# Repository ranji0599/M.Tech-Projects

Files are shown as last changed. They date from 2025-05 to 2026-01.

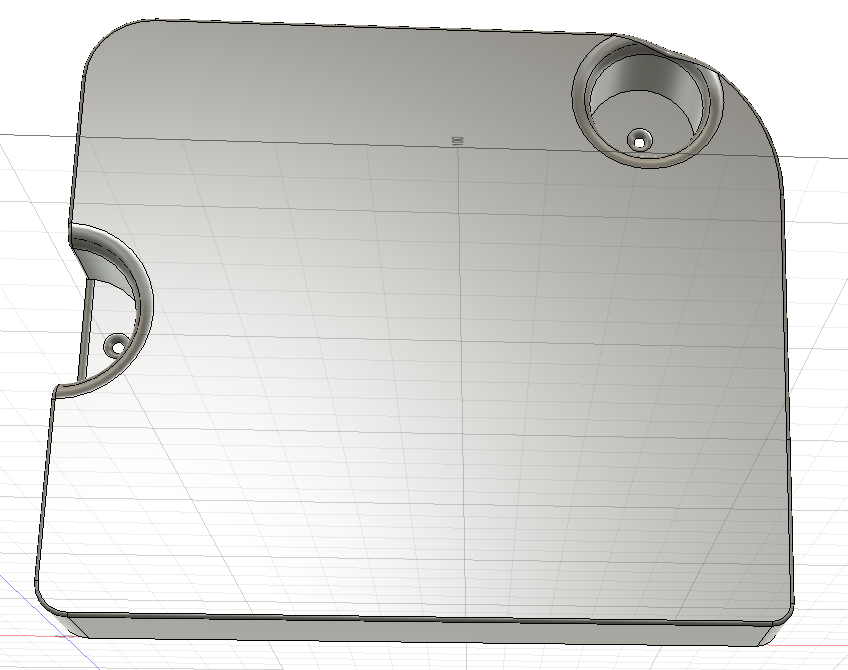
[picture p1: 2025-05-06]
Fusion 360/PNG/Screenshot 2025-03-03 040742.png

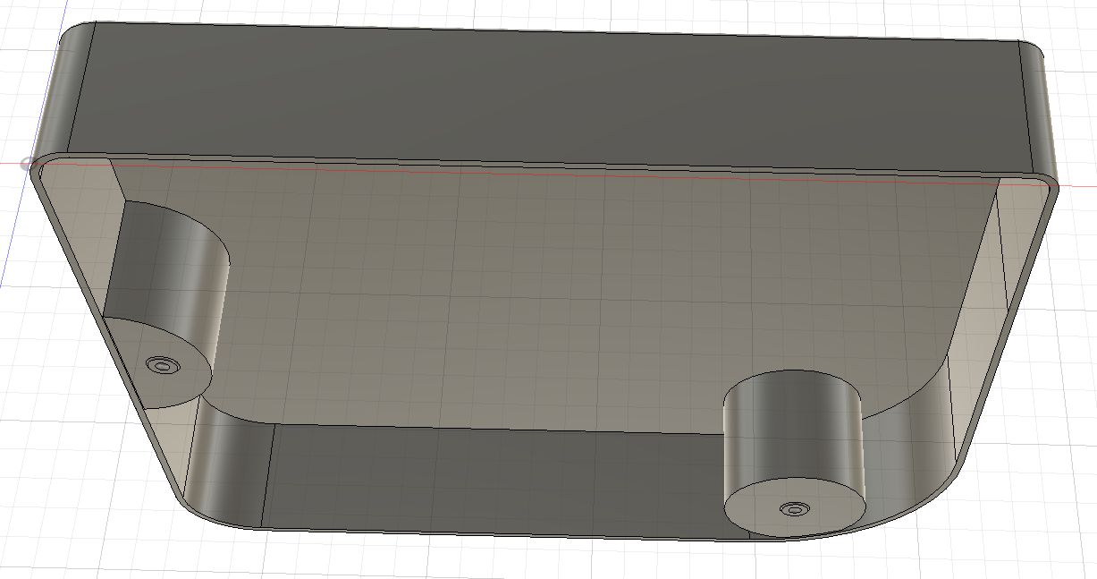
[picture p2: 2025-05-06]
Fusion 360/PNG/Screenshot 2025-03-03 040723.png

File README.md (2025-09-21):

Smart Bed for Pressure Ulcer Prevention

License: MIT Status: Development

IoT-enabled smart bed system that prevents pressure ulcers through automated monitoring and intervention.
Problem

    57-60% of hospitalized patients develop pressure ulcers
    Manual repositioning every 2 hours is labor-intensive
    Current solutions are expensive or require constant monitoring

Solution

Smart bed with automated pressure redistribution using:

    Real-time monitoring: 6 BME280 sensors track pressure, temperature, humidity
    Micro-vibrations: 25-50Hz vibrations improve blood circulation
    Auto-repositioning: Servo motors provide gentle lateral movements
    No manual intervention: Algorithm-driven responses to risk thresholds

Hardware

    ESP32 microcontroller
    6x BME280 sensors
    6x Vibration motors (ERM)
    2x SG90 servo motors
    7.4V LiPo battery
    SD card for data logging

Getting Started
Clone repository:

git clone https:https://github.com/ranji0599/Bed-Sores-Monitoring-Prevention

    Install Thonny IDE and ESP32 support
    Wire components per circuit diagram
    Upload firmware to ESP32
    Mount sensors on bed surface

Project Structure

    Code: Main control program in src/ folder
    Components: Complete parts list in Docs/Components
    Circuit Design: KiCAD files in Hardware/circuit-design/
    3D Casing: Fusion360 models in Hardware/casing/
    Documentation: Project docs in Docs/ folder

License

MIT License - see LICENSE file

⚠️ Disclaimer: Research prototype for educational purposes. Clinical validation required before medical use.

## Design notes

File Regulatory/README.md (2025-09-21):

# Bedsore Monitoring & Prevention System  

This repository contains **regulatory documentation samples** and **technical files** for a TRL-4 prototype developed at IIT Guwahati.  
The project focuses on preventing **pressure ulcers (bedsores)** through continuous monitoring of high-pressure regions.  

## Project Highlights
- Electronics and PCB designed using **KiCAD & Fusion 360**.  
- Firmware implemented on microcontrollers with real-time monitoring and alerts.  
- Documentation aligned with **FDA Class II**, **EU MDR Class IIa**, and **CDSCO monitoring device** pathways.  

## Repository Structure
- `Technical_Dossier.md` – Device description, intended use, and regulatory pathway mapping.  
- `Usability_Engineering_Report.md` – Human factors engineering analysis.  
- `Risk_Management_File_ISO14971.md` – Hazard identification and control measures.  
- `Verification_Validation_Plan.md` – Verification and validation framework for sensors and alarms.  

## Disclaimer
These documents are **mock regulatory files** created for academic demonstration and are not official submissions.

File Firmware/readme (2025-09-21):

This contains a code which I had used for programming ESP32 Microcontroller using MicroPython program on Thonny IDE.

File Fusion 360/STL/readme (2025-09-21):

Contains STL files required for 3D CAD printing of Electronic Enclosures

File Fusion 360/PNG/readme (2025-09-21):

Contains the snapshots of various components and technical detials of the CAD designs

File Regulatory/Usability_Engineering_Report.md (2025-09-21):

# Usability Engineering File  

- **User Groups:** Nurses, caregivers, bedridden patients.  
- **Hazards Identified:** Alarm fatigue, misinterpretation of signals.  
- **Mitigation Measures:** Intuitive UI, training manual, low-false-alarm design.

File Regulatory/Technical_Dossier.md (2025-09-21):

# Technical Dossier – Bedsore Monitoring System  

## Device Description  
Wearable system for continuous monitoring of pressure points to prevent bedsores.  

## Design Overview  
- Sensors integrated into mattress overlay.  
- Electronics & firmware for real-time data logging and alerting.  

## Regulatory Pathways  
- US FDA: Class II (pressure ulcer prevention device).  
- EU MDR: Class IIa.  
- CDSCO: Medical Device (monitoring category).

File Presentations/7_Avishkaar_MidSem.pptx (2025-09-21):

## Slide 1

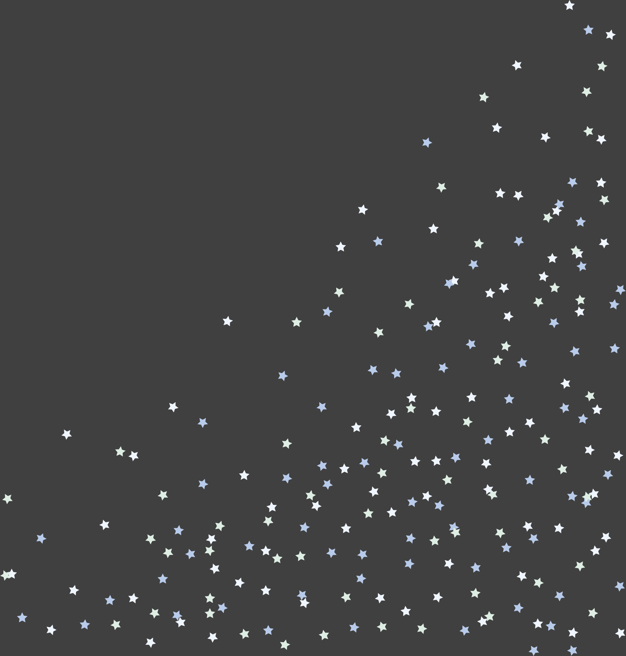
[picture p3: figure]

Smart bed for pressure ulcers (Bedsores) prevention

(Group 7: Avishkaar)

Mid-Semester Evaluation (HT508)

Sharvani Pokala, Ranjith K S, Sudheshna Ch, Rushikesh Khot

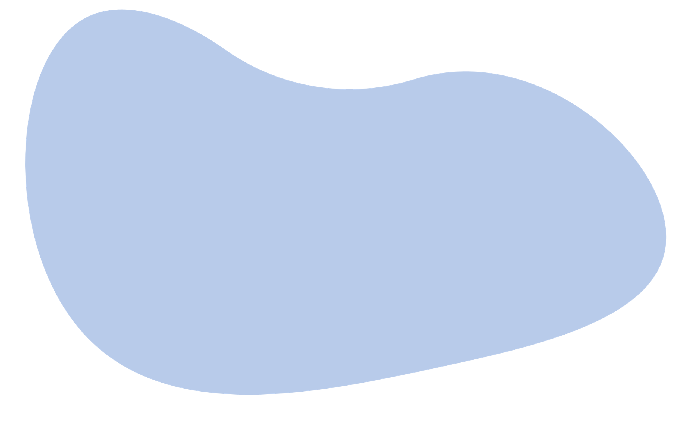
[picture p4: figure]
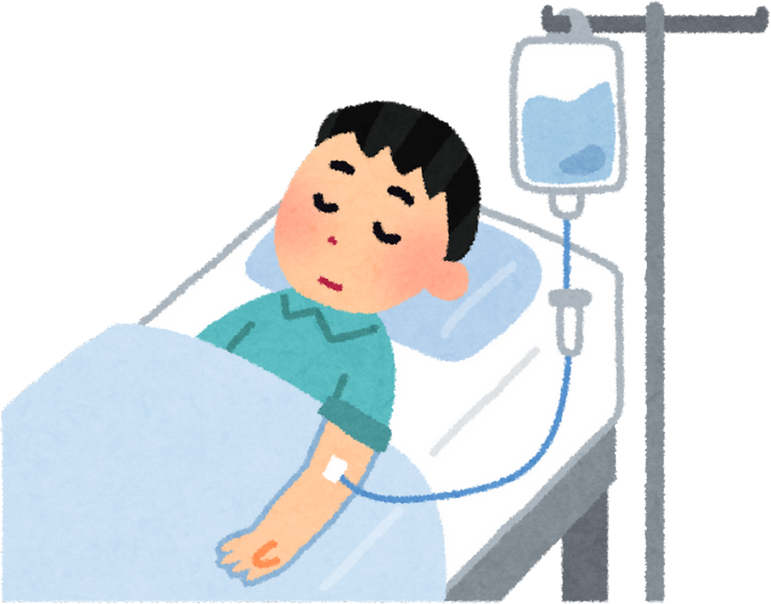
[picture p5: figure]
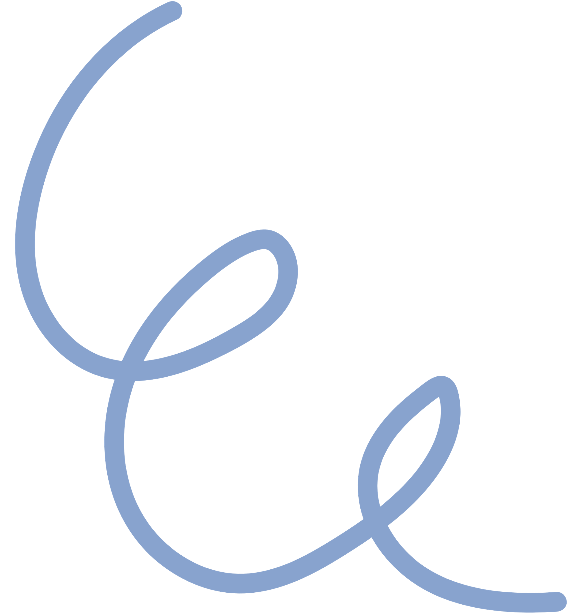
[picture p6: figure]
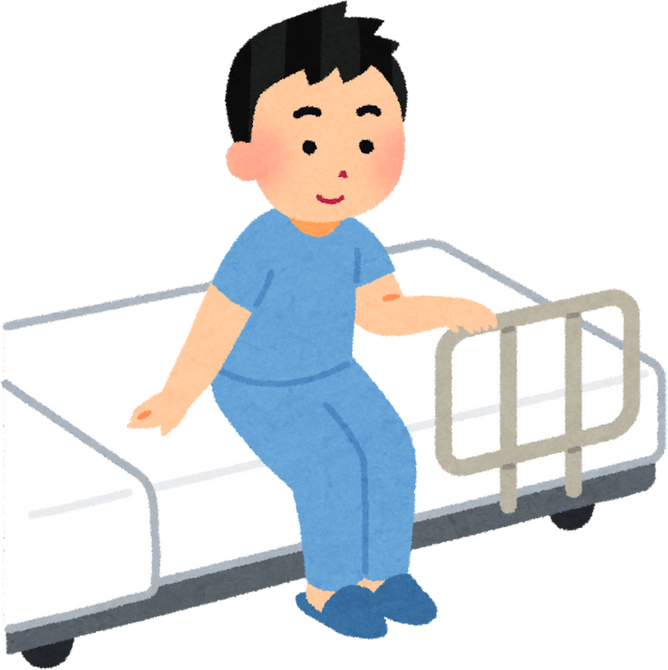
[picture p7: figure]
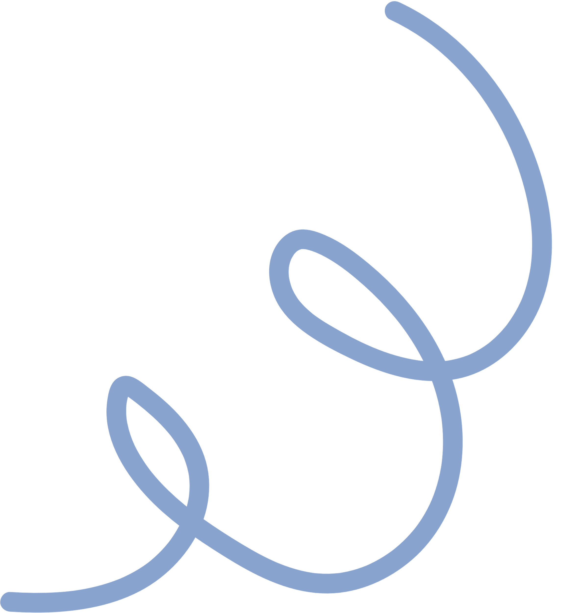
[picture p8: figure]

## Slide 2

Problem Statement

Bedsores are a critical issue for bedridden patients due to prolonged pressure on the skin, leading to tissue damage and infection. Existing beds and care systems fail to provide real-time monitoring, pressure redistribution, and timely intervention, resulting in poor patient outcomes and increased caregiver burden.

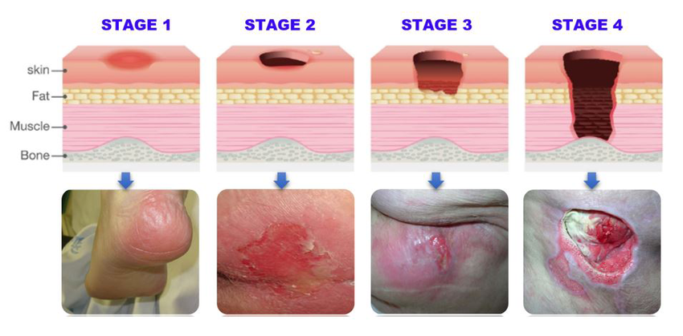
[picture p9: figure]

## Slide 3

Severity of the problem (Survey)

Sample size: 12 individuals

Question: Have you encountered bedsores during the time of hospitalisation?

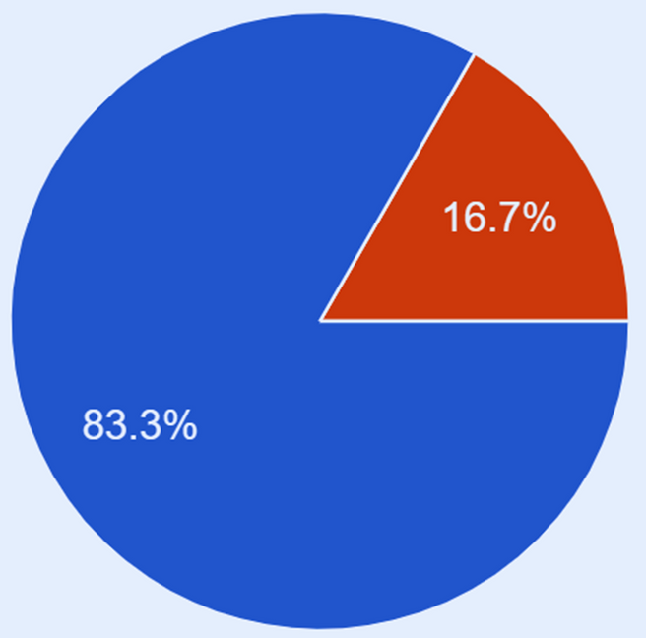
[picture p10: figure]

Yes: 10 individuals; No: 2 individuals

Question: Time taken to heal the bed sores.

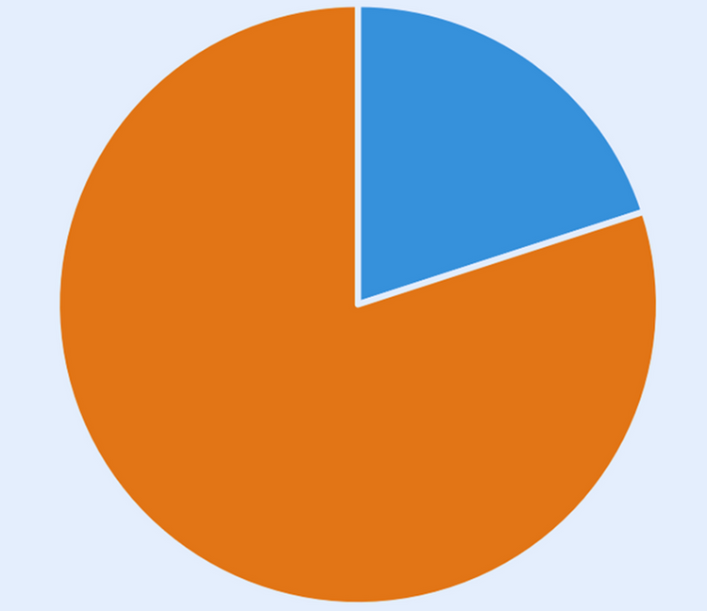
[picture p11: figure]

More than 7 days: 8 individuals
Upto 7 days: 2 individuals

Upto 7 days
(2 people)

No
(2 people)

Yes
(10 people)

More than 7 days
(8 people)

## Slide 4

Severity of the problem (Doctor’s Input)

- Bedsores are a major concern for patients and play a vital role in patient care and management.
- Various methods have been developed to address this issue, but they are only applied after bedsores have already formed.
- Currently, multiple beds and mattresses are available that claim to prevent bedsores.
- However, all of these solutions require manual intervention, making them challenging to manage.
- Eliminating the need for manual intervention is essential, as it saves time, labor, and costs while enhancing patient care.
- Incorporating features that improve blood circulation can further help in preventing bedsores.
Dr. Rakesh Salunkhe
Dr. Shrinivas Vidhmvar
(Govt Medical College, Latur, Maharastra)

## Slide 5

Literature Review

1. Reasons for pressure ulcers:
- Prolonged and uneven pressure distribution
- Changes in blood supply to the dermal tissue (The normal capillary pressure ranges from 16 to 33 mm Hg in different segments. External pressure of more than 33 mm Hg occludes the blood vessel so that the underlying tissues become anoxic and if the pressure continues for a critical duration, cell death and eventual result in ulceration.)
- Shearing
- Friction
- Moisture
- Malnutrition
- Position
2. What happens if not treated?
- Mortality
- Sepsis
- Osteomyelitis
- Amputation
3. Statistics!
- Incidence rates differ from ward to ward.
- 50% patients with spinal cord injuries suffer from pressure ulcers, which causes death of almost 10% of the patients.
- 70% of patients older than 70 years experience pressure ulcers.

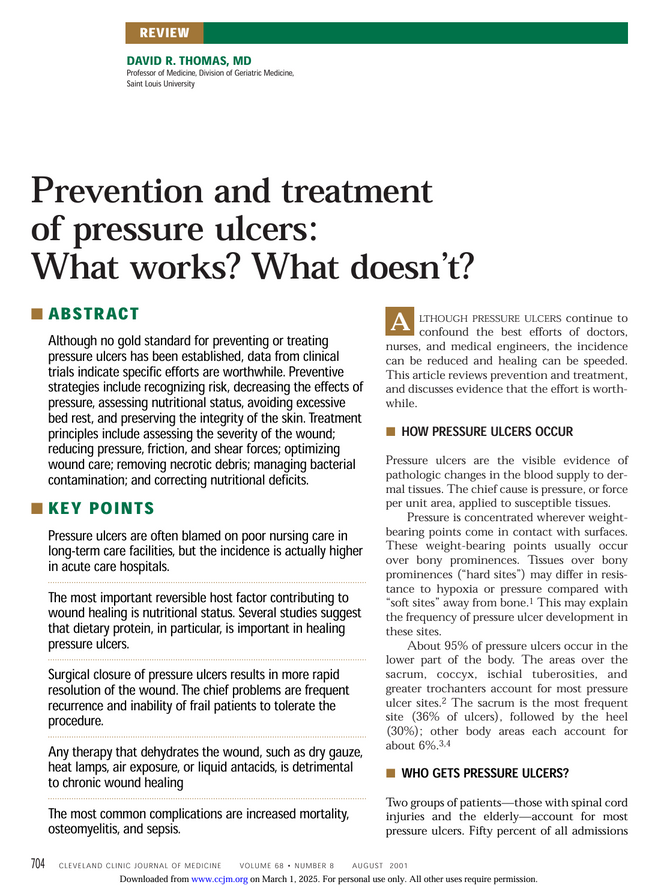
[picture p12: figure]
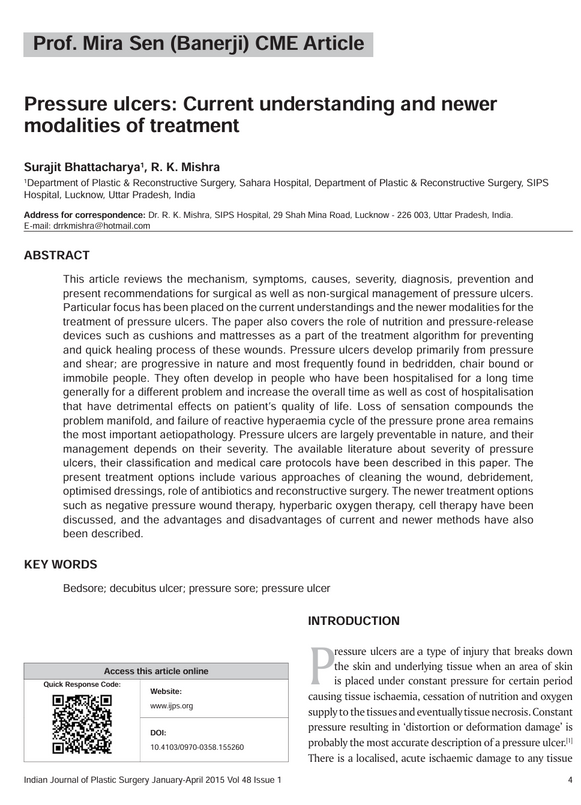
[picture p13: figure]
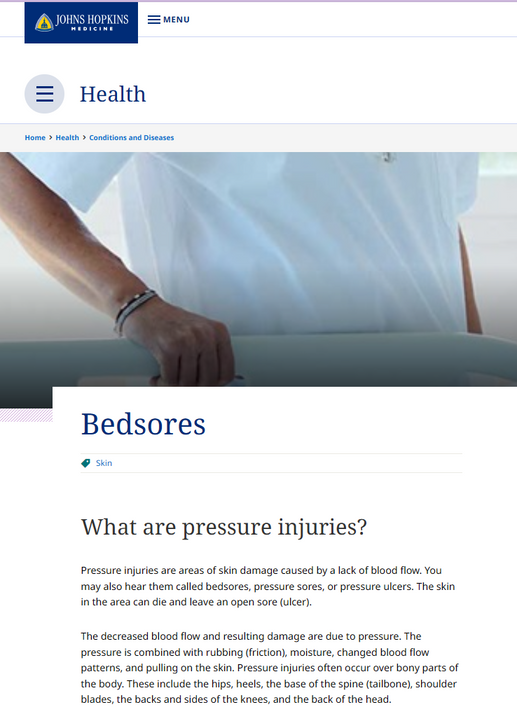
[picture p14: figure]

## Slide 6

Diagram showing the areas of the body at risk of pressure sores when lying down.

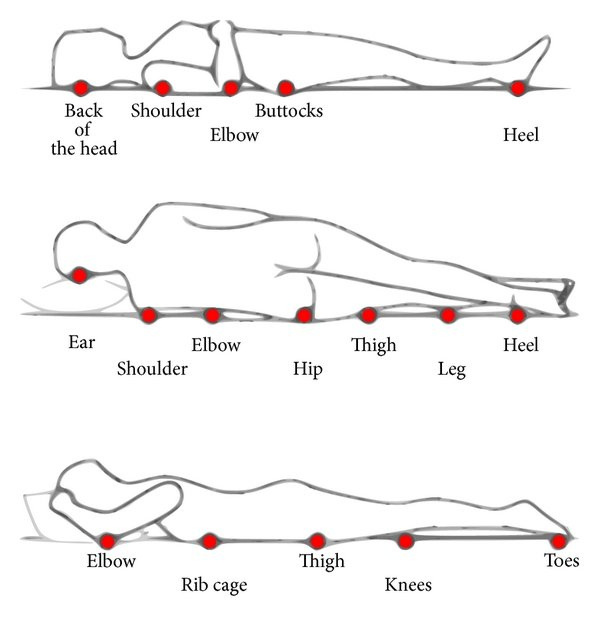
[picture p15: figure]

Source: https://www.researchgate.net/figure/Diagram-showing-the-areas-of-the-body-at-risk-of-pressure-sores-when-lying-down_fig7_258029663

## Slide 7

Literature Review

Table: Overview of existing technologies for pressure sores management

S No. | Title | Year | Advantages | Disadvantages
1. | Evaluation of commodity force sensor for building low-cost bed sore prevention mat. | 2021 | Pressure monitoring for every 30 seconds. | Can’t decide the movements of patient. Requires manual intervention.
2. | Wearable Preventive Pressure Ulcer System Using Embroidered Textile Electrodes | 2023 | Non-invasive & wearable. Activates muscles to relieve pressure | Not effective for existing severe ulcers.
3. | IoT-Based Healthcare Monitoring System: Bedsores Prevention | 2020 | Real-time pressure detection | Requires constant monitoring. Dependent on internet connectivity
4. | Medical Robotic Bed to Prevent Pressure Sores | 2021 | Fully automated repositioning | Expensive due to robotic implementation

Table: Threshold values with respect to pressure, temperature and humidity

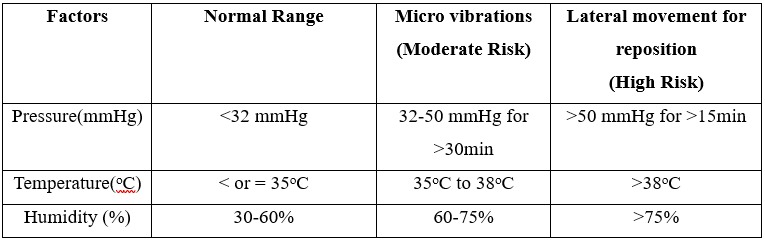
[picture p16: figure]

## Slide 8

Proposed Solution

To develop a smart bed with integrated sensors, automated pressure redistribution, and caregiver-friendly interfaces to prevent bedsores, improve patient care, and reduce healthcare costs.
The proposed smart bed has features like:
    - Integrated sensors and motors: These are equipped with sensors to monitor pressure, temperature, and moisture in real-time, identifying conditions contributing to bedsores.
    - No manual intervention: The algorithm ensures that the patient's position is changed occasionally based on the requirement without requiring any manual intervention.
    - This bed tries to detect the pressure load by utilizing the in-built pressure sensors, thereby instructing the algorithm to alter the bed direction and create micro-vibrations, which facilitates the change in the position of the patient and ensures proper blood flow.
    - The moisture detection sensors help in keeping the bed surfaces dry, thereby preventing microbial colonization which could lead to further infections.

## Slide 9

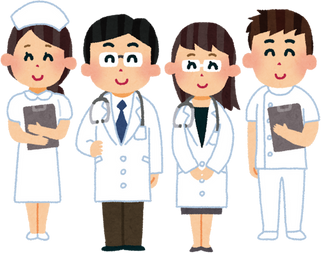
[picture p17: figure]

Block Diagram

Bed

Actuators
(Microvibrations
lateral Movement)

ESP 32

BME 280

Mux

SD Card

Real Time

Power Source

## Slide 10

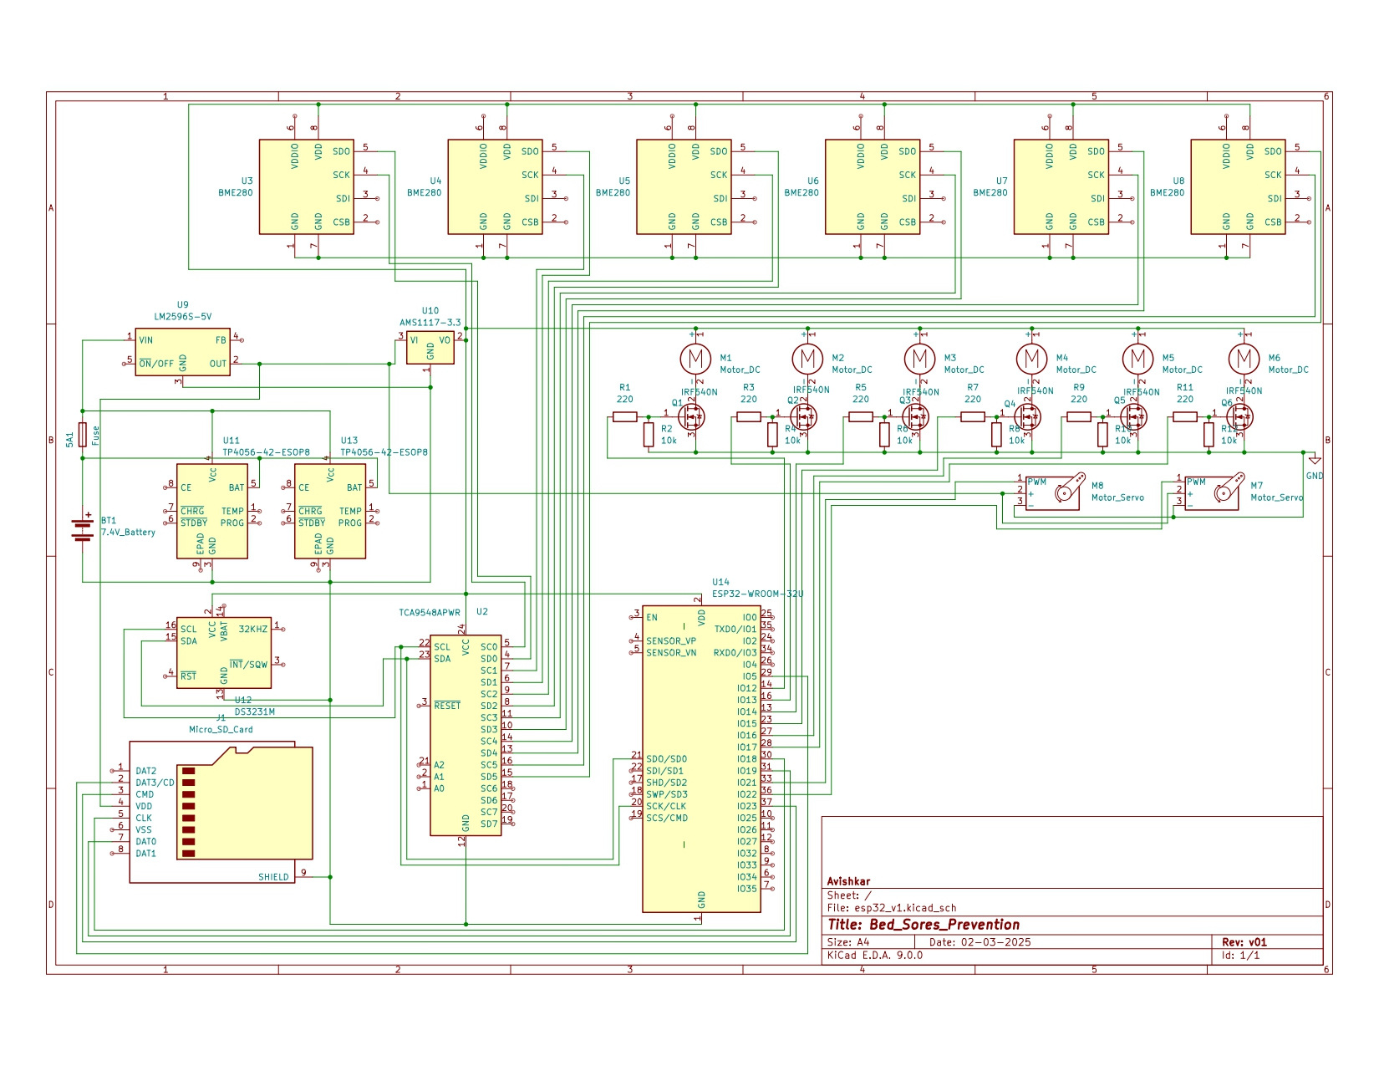
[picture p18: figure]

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
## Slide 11

Casing design (Fusion360)

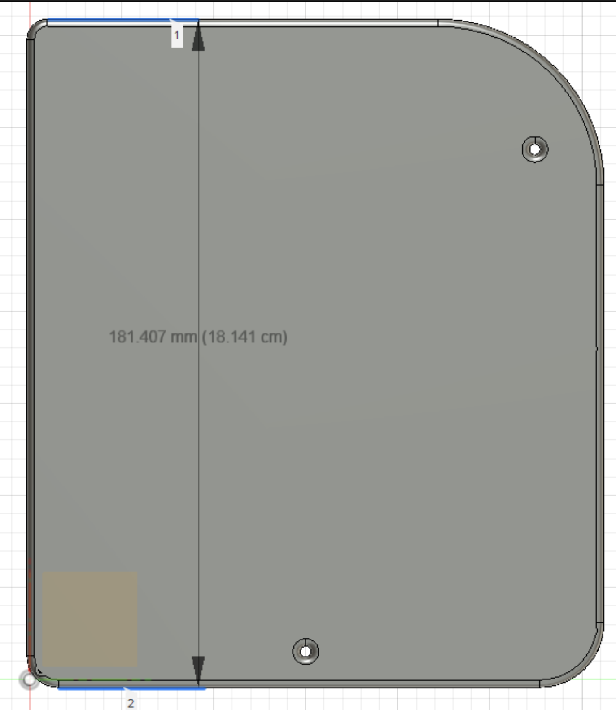
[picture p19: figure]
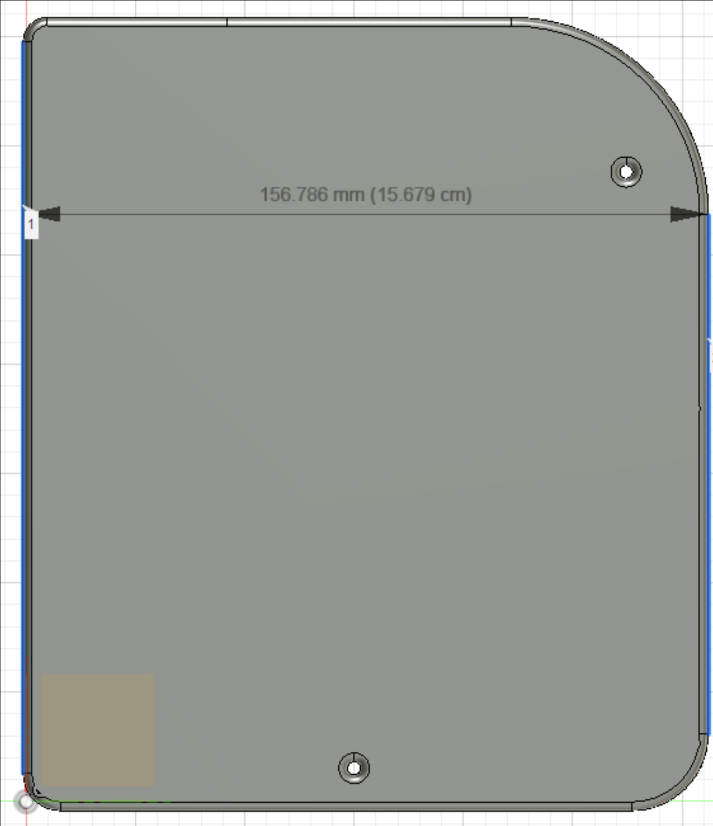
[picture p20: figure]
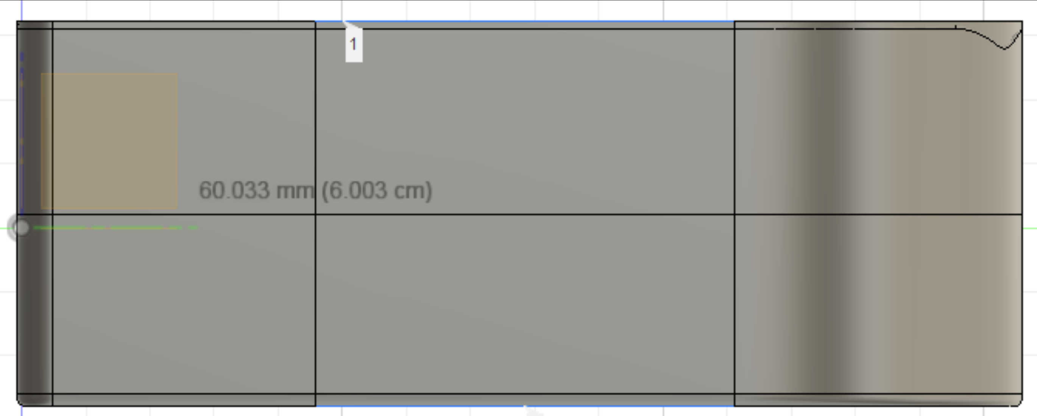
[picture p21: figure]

Fig: Bottom and side view of the casing
(Length = 18.141cm, Width = 15.679cm, Height = 6.003cm)

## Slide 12

Casing design (Fusion360)

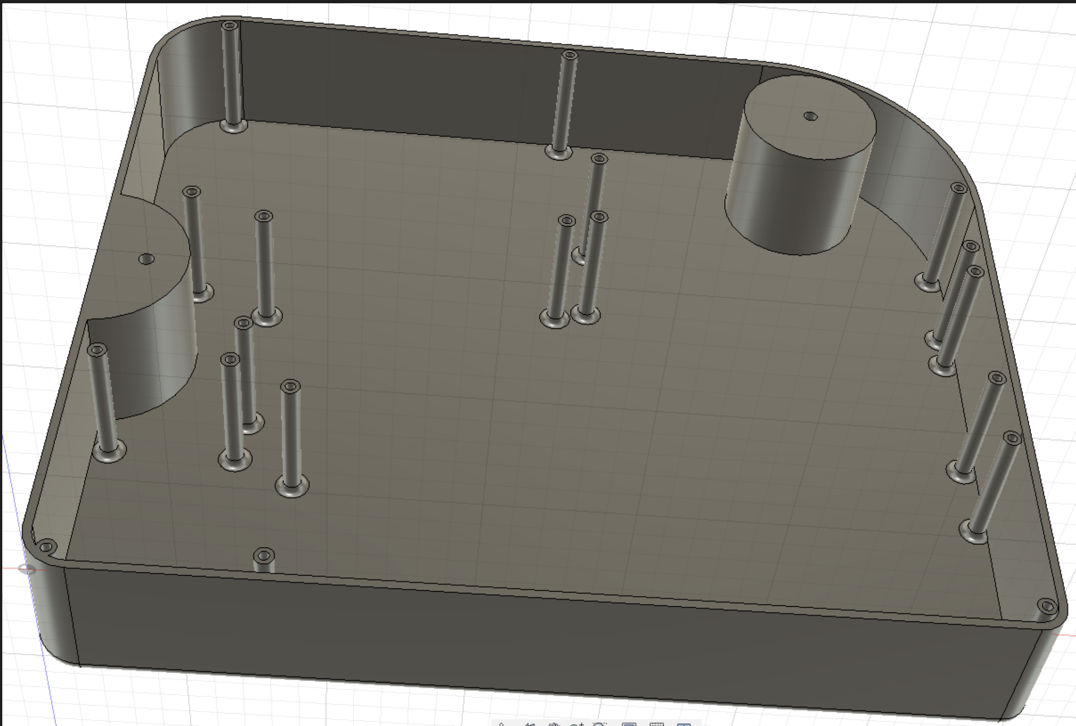
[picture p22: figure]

(a)

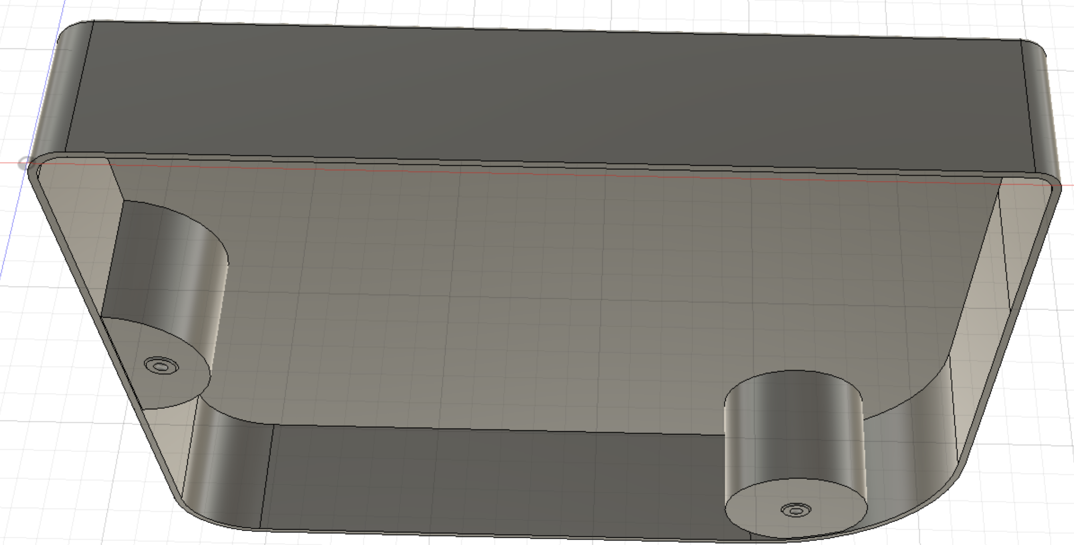
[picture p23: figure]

(b)

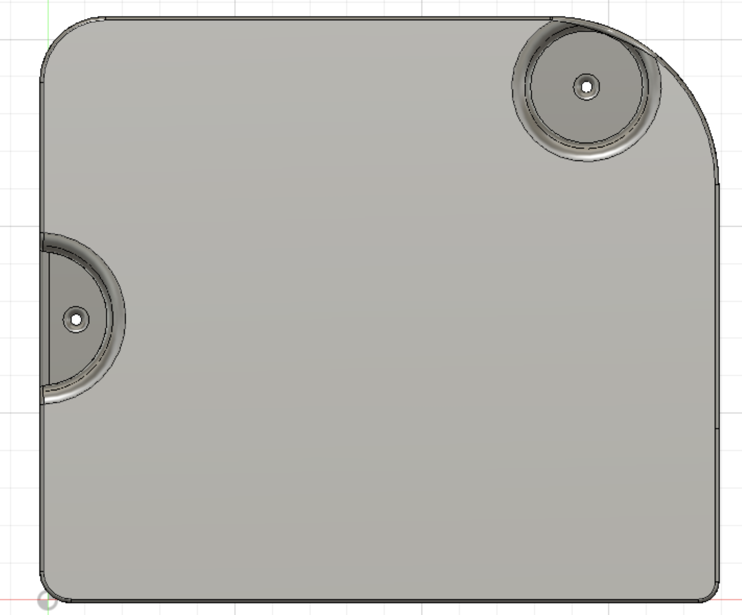
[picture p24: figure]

(c)

Fig: (a) Bottom inside (b) top inside (c) top outside

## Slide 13

Components List (Robu.in)

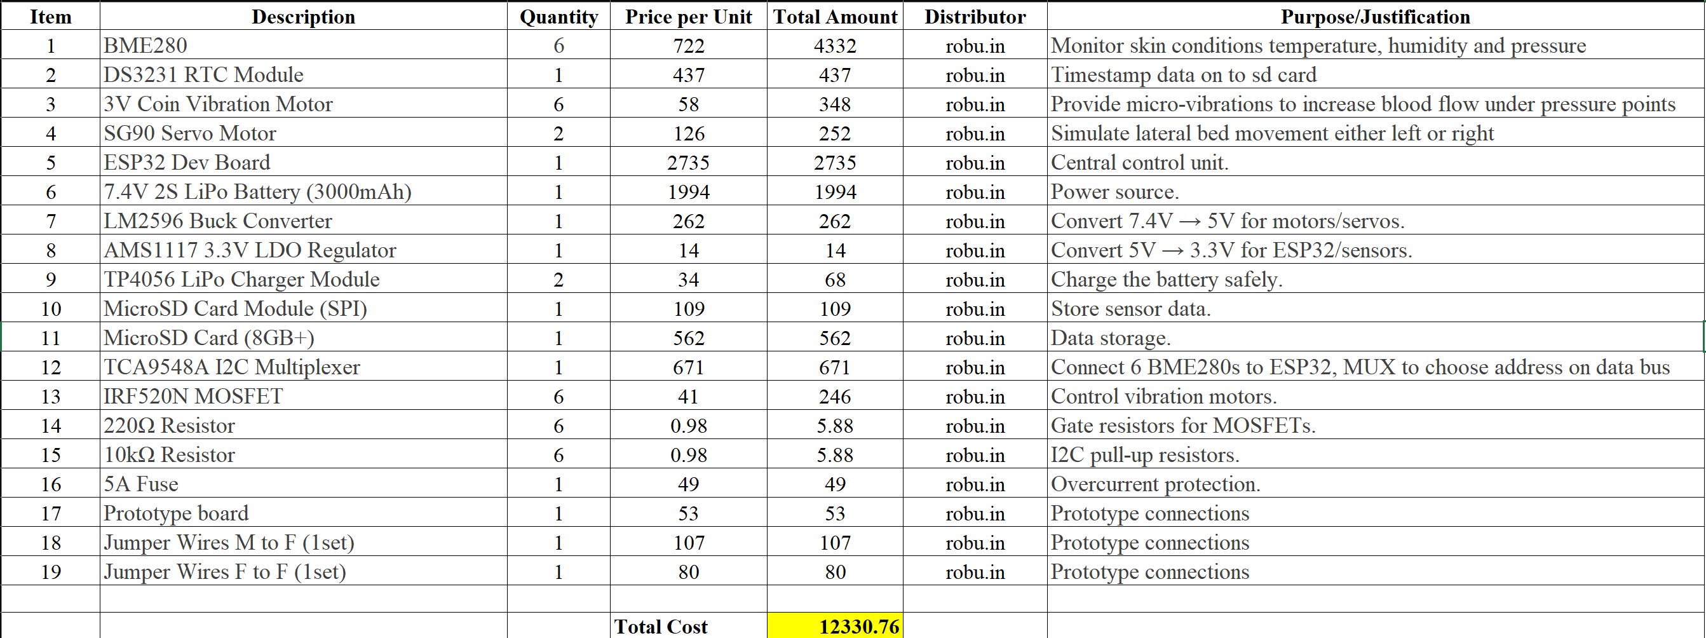
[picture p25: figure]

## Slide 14

Gantt Chart

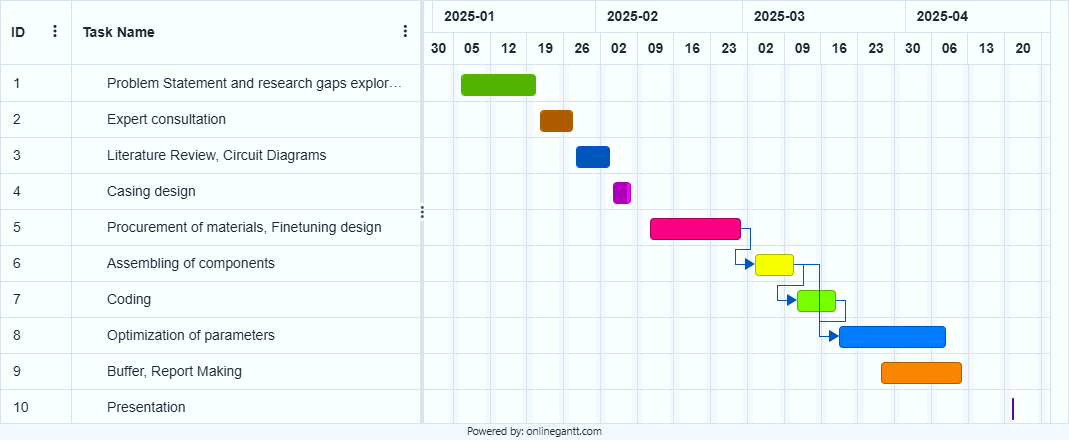
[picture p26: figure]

Completed

Completed

Completed

Completed

0% Completed

Finish-Start

Finish-Start

0% Completed

Finish-Start

0% Completed

0% Completed

0% Completed

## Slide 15

Thank You

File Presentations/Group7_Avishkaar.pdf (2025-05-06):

## Jyoti and Bhupat Mehta School of Health Science and Technology Indian Institute of Technology, Guwahati 781039 Guwahati, Assam, India

# Smart bed for pressure ulcers (bedsores) prevention

Jyoti and Bhupat Mehta School of Health Science and Technology, Indian Institute of Technology Guwahati, India

www.iitg.ac.in

Figure: Stages of pressure ulcers

## Sharvani Pokala, K S Ranjith Kumar, Sai Hari Hara Sudheshna Chunduru, Rushikesh Khot

### Motivation

Bedsores, caused by prolonged pressure on the skin, are a serious healthcare challenge, leading to severe complications.
They are often prominent in bedridden or immobile individuals.
Pressure ulcers significantly increase healthcare costs by demanding
prolonged hospitalization, advanced wound care, and manual intervention.
This highlights the need for automated systems that enhance circulation
and reduce time, labor, and costs. | Figure: Prevalence of Pressure

### ulcers State of the art technologies available

Figure: Wired sensor mat | Figure: Robotic bed

### Core technological idea

Figure: Key pressure points on different segments of the body

Figure: Weight distribution at risk points

Figure: Threshold parameters

### Implementation & Achievements

Figure: Circuit diagram for the prototype

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
Figure: Vibration motors required after calculations

Figure: Vibration motor

### Outlook

Apply patient-specific data to train ML models for tailored prevention. Develop a user interface (UI) to display real-time data and generate analytical plots for insights.
Enhance therapeutic outcomes by integrating antimicrobial patches at targeted pressure points
Optimize ergonomic support to maximize comfort and efficacy.

### References

Kaewjamnong, S., & Hongwitayakorn, A. (2021). Evaluation of a commodity force sensor for building a low-cost bedsore prevention mat. Science, Engineering and Health Studies, 21020003-21020003. DOI: https://doi.org/10.14456/sehs.2021.13
Palumbo, F., Barsocchi, P., Furfari, F., & Ferro, E. (2013). AAL middleware infrastructure for green
bed | activity | monitoring. | Journal | of | Sensors, | 2013(1), | 510126. | DOI:
https://doi.org/10.1155/2013/510126
Seon, M., Lee, Y., & Moon, C. (2021). Medical robotic bed to prevent pressure sores. Applied Sciences, 11(18), 8459. DOI: https://doi.org/10.3390/app11188459

### Reflection & Conclusion

Gained hands-on experience in developing a smart bed prototype using tools like KiCAD, Fusion 360, and ESP32 with
MicroPython, | integrating | electronics | and | mechanical
components effectively.
Addressed a critical healthcare issue—pressure ulcer prevention —by designing a solution that combines sensor data, threshold analysis, and targeted vibration therapy to improve patient outcomes.
Learned to select and interface electronic components based on power and functionality, and performed circuit assembly, debugging, and testing in a lab environment.
Gained experience working in interdisciplinary teams combining biomedical engineering, design, and clinical application perspectives.

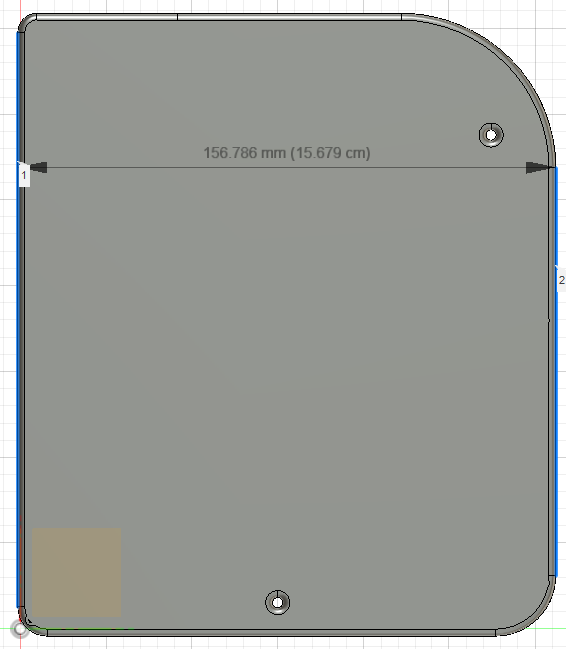
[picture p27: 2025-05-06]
Fusion 360/PNG/Screenshot 2025-03-03 035934.png

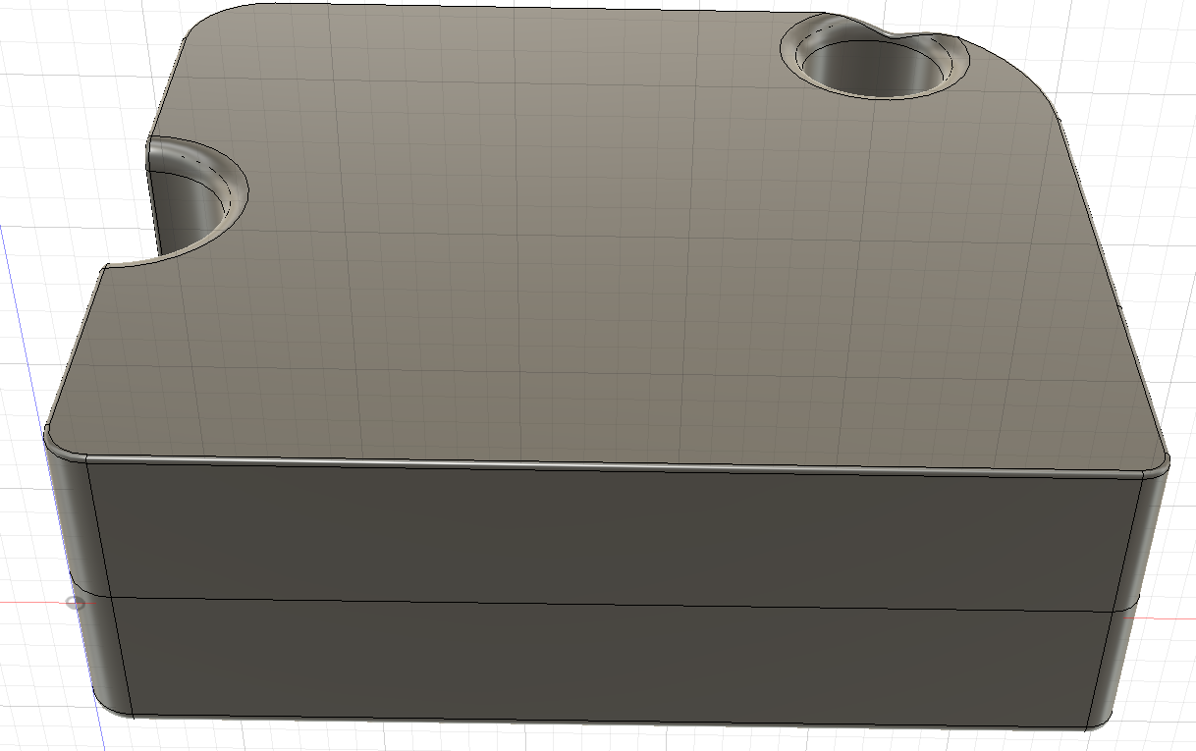
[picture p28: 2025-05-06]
Fusion 360/PNG/Screenshot 2025-03-03 040820.png

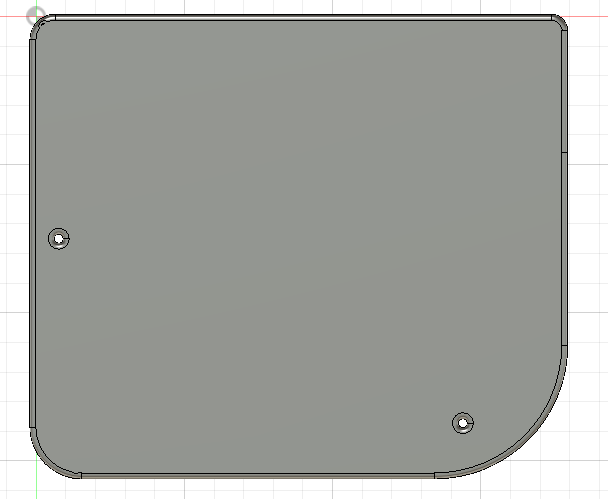
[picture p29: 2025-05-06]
Fusion 360/PNG/Screenshot 2025-03-03 040906.png

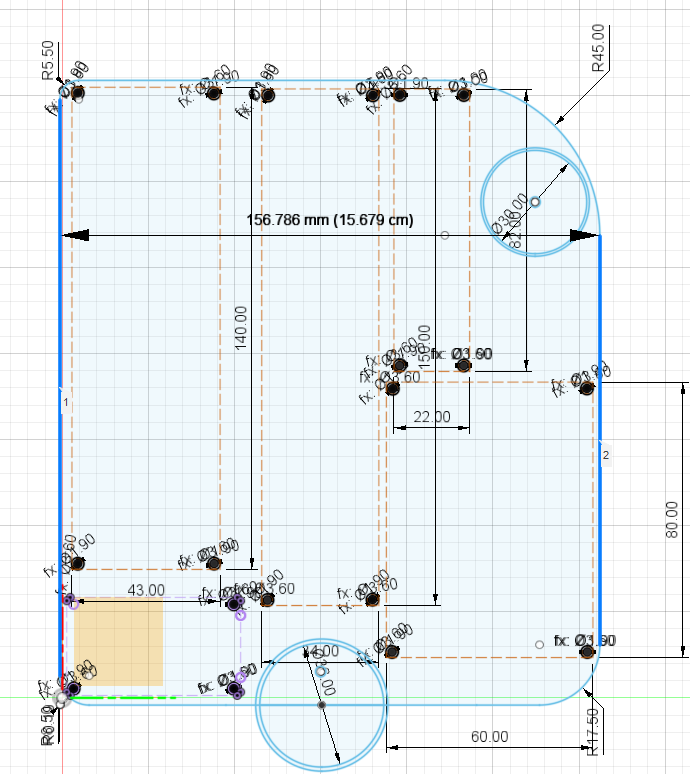
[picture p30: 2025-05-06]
Fusion 360/PNG/Screenshot 2025-03-03 035726.png

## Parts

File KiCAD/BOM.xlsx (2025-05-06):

Aavishkar | Sl. No | Components | Quantity | Unit Price | Total Price | Vendor | Link
 | 1 | 18650 Polymer Lithium Ion Charger Type C to 2S 8.4V 2A Booster Module | 1 | 261 | 261 | robu.in | https://robu.in/product/18650-polymer-lithium-ion-charger-type-c-to-2s-8-4v-2a-booster-module/
 | 2 | 2S 3A Li-ion Lithium Battery 7.4V 8.4V 18650 Charger Protection Board Module | 1 | 42 | 42 | robu.in | https://robu.in/product/2s-3a-li-ion-lithium-battery-7-4v-8-4v-18650-charger-protection-board-module/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
 | 3 | 2 Way Slide Switch 2.54mm Pitch (Pack of 5) | 1 | 59 | 59 | robu.in | https://robu.in/product/2-way-slide-switch-2-54mm-pitch-pack-of-5/
 | 4 | Amass XT60H Male Connector with Housing – XT60H-M.G.Y | 1 | 37 | 37 | robu.in | https://robu.in/product/xt60h-connector-with-housing-male/
 | 5 | Seeed Studio Grove 4 pin Male Jumper to Grove 4 pin Conversion Cable 20cm(Pack of 5) | 2 | 156 | 312 | robu.in | https://robu.in/product/grove-4-pin-male-jumper-to-grove-4-pin-conversion-cable-20cm/
 | 6 | LM2596 HV DC-DC Buck Converter 4.5-40V to 3-35V Adjustable Step Down Module | 1 | 73 | 73 | robu.in | https://robu.in/product/lm2596-hv-dc-dc-buck-converter-4-5-50v-to-3-35v/
 | 7 | 1×40 Right Angle Male Berg Strip Connector-5 pcs. | 1 | 44 | 44 | robu.in | https://robu.in/product/1x40-right-angle-male-berg-strip-connector/
 | 8 | IRLZ44NPBF | 10 | 75.57 | 755.7 | element14 | https://in.element14.com/infineon/irlz44npbf/mosfet-n-55v-41a-to-220/dp/8651418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|pcrid||plid||kword||match||slid||product||pgrid||ptaid||&gad_source=1

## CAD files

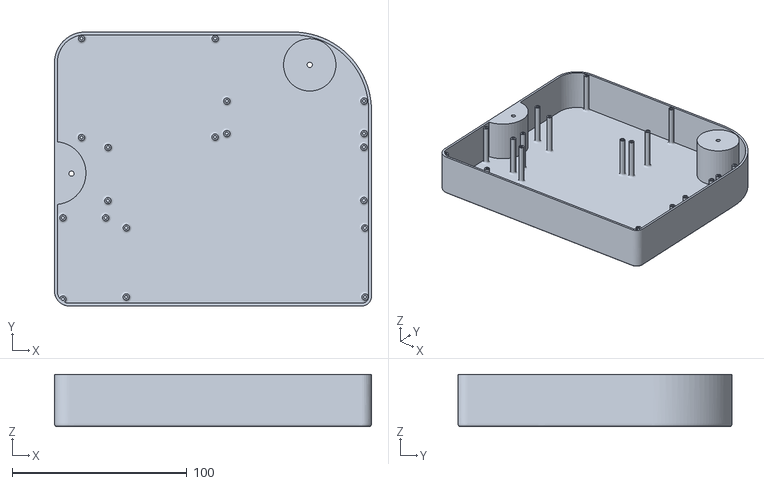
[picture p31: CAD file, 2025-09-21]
Fusion 360/STL/bottom_asci.stl
181.4 x 156.8 x 30.0

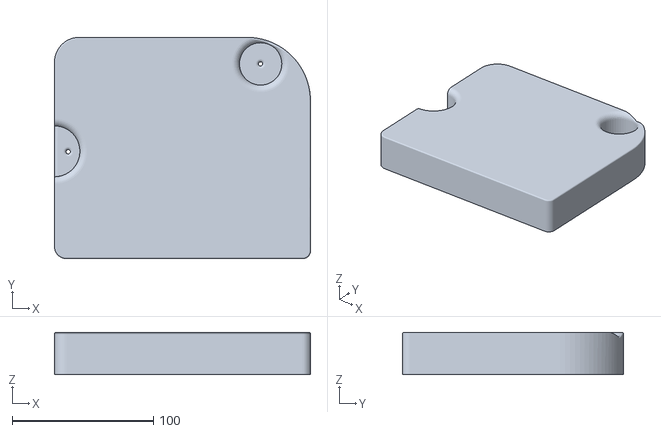
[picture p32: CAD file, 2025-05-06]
Fusion 360/STL/altered body.stl
181.4 x 156.8 x 30.0

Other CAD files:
Fusion 360/STL/bottom.stl
Fusion 360/STL/top.stl

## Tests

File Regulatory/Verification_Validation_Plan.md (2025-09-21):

# Verification & Validation Plan  

- **Verification:** PCB electrical testing, firmware debug, sensor calibration.  
- **Validation:** Usability tests with simulated patients.  
- **Acceptance Criteria:** >95% sensor accuracy, <2s alarm delay.

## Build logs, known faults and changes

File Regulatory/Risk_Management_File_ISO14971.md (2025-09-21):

# Risk Management – ISO 14971  

| Hazard | Cause | Effect | Control Measure | Residual Risk |
|---|---|---|---|---|
| Sensor failure | Hardware fault | Missed ulcer risk | Redundancy, periodic calibration | Low |
| Alarm not audible | Low volume | Delayed intervention | Adjustable volume, visual alert | Low |

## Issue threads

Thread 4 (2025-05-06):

KiCAD

ranji0599, 2025-05-06:
[Final Bed Sores KiCAD drawing.pdf](https://github.com/user-attachments/files/20054318/Final.Bed.Sores.KiCAD.drawing.pdf)

Closed 2025-05-06.

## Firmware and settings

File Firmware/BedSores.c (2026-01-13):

// I2C
#define I2C_SDA_GPIO      21
#define I2C_SCL_GPIO      22

// Vibration Motor
#define MOTOR_GPIO        13

// Servo (PWM)
#define SERVO_GPIO        12

// SD Card (SPI)
#define SD_MOSI_GPIO      23
#define SD_MISO_GPIO      19
#define SD_SCLK_GPIO      18
#define SD_CS_GPIO        5
#include <stdio.h>
#include <string.h>
#include <stdbool.h>

#include "freertos/FreeRTOS.h"
#include "freertos/task.h"

#include "driver/gpio.h"
#include "driver/i2c.h"
#include "driver/ledc.h"
#include "driver/spi_master.h"

#include "esp_log.h"
#include "esp_err.h"

#include "sdmmc_cmd.h"
#include "esp_vfs_fat.h"

/* ===================== SYSTEM CONFIG ===================== */
#define TAG "BEDSORE_SYS"

#define NUM_SENSORS                 8

#define TEMP_THRESHOLD_C            32.0f
#define PRESSURE_THRESHOLD_HPA      1001.0f
#define HUMIDITY_THRESHOLD_PCT      80.0f

#define I2C_MUX_ADDR                0x70
#define BME280_ADDR                 0x76
#define RTC_ADDR                    0x68

/* ===================== I2C INIT ===================== */
static void i2c_init(void)
{
    i2c_config_t conf = {
        .mode = I2C_MODE_MASTER,
        .sda_io_num = I2C_SDA_GPIO,
        .scl_io_num = I2C_SCL_GPIO,
        .sda_pullup_en = GPIO_PULLUP_ENABLE,
        .scl_pullup_en = GPIO_PULLUP_ENABLE,
        .master.clk_speed = 100000
    };
    i2c_param_config(I2C_NUM_0, &conf);
    i2c_driver_install(I2C_NUM_0, conf.mode, 0, 0, 0);
}

/* ===================== I2C MUX ===================== */
static void mux_select(uint8_t channel)
{
    uint8_t data = (1 << channel);
    i2c_master_write_to_device(I2C_NUM_0,
                               I2C_MUX_ADDR,
                               &data,
                               1,
                               pdMS_TO_TICKS(100));
}

/* ===================== SENSOR READ (SIMPLIFIED) ===================== */
typedef struct {
    float temperature;
    float pressure;
    float humidity;
} sensor_data_t;

/* Placeholder read (replace with full BME280 driver later) */
static void read_bme280(sensor_data_t *data)
{
    data->temperature = 33.0f;
    data->pressure    = 1005.0f;
    data->humidity    = 82.0f;
}

/* ===================== MOTOR ===================== */
static void motor_init(void)
{
    gpio_config_t io_conf = {
        .pin_bit_mask = (1ULL << MOTOR_GPIO),
        .mode = GPIO_MODE_OUTPUT
    };
    gpio_config(&io_conf);
    gpio_set_level(MOTOR_GPIO, 0);
}

static void motor_vibrate(uint32_t duration_ms)
{
    gpio_set_level(MOTOR_GPIO, 1);
    vTaskDelay(pdMS_TO_TICKS(duration_ms));
    gpio_set_level(MOTOR_GPIO, 0);
}

/* ===================== SERVO (LEDC PWM) ===================== */
static void servo_init(void)
{
    ledc_timer_config_t timer = {
        .speed_mode       = LEDC_LOW_SPEED_MODE,
        .timer_num        = LEDC_TIMER_0,
        .duty_resolution  = LEDC_TIMER_16_BIT,
        .freq_hz          = 50,
        .clk_cfg          = LEDC_AUTO_CLK
    };
    ledc_timer_config(&timer);

    ledc_channel_config_t channel = {
        .gpio_num   = SERVO_GPIO,
        .speed_mode = LEDC_LOW_SPEED_MODE,
        .channel    = LEDC_CHANNEL_0,
        .timer_sel  = LEDC_TIMER_0,
        .duty       = 0
    };
    ledc_channel_config(&channel);
}

static void servo_set_angle(uint16_t angle)
{
    if (angle > 180) angle = 180;

    uint32_t duty = (500 + (angle * 2000 / 180)) * 65535 / 20000;
    ledc_set_duty(LEDC_LOW_SPEED_MODE, LEDC_CHANNEL_0, duty);
    ledc_update_duty(LEDC_LOW_SPEED_MODE, LEDC_CHANNEL_0);
    vTaskDelay(pdMS_TO_TICKS(300));
}

static void lateral_movement(void)
{
    servo_set_angle(45);
    motor_vibrate(200);

    servo_set_angle(90);
    motor_vibrate(200);

    servo_set_angle(135);
    motor_vibrate(200);

    servo_set_angle(90);
}

/* ===================== SD CARD ===================== */
static void sdcard_init(void)
{
    esp_vfs_fat_sdmmc_mount_config_t mount_config = {
        .format_if_mount_failed = false,
        .max_files = 5
    };

    sdmmc_card_t *card;
    sdmmc_host_t host = SDSPI_HOST_DEFAULT();
    spi_bus_config_t bus_cfg = {
        .mosi_io_num = SD_MOSI_GPIO,
        .miso_io_num = SD_MISO_GPIO,
        .sclk_io_num = SD_SCLK_GPIO,
        .max_transfer_sz = 4000
    };

    spi_bus_initialize(host.slot, &bus_cfg, SDSPI_DEFAULT_DMA);
    sdspi_device_config_t slot_config = SDSPI_DEVICE_CONFIG_DEFAULT();
    slot_config.gpio_cs = SD_CS_GPIO;

    esp_vfs_fat_sdspi_mount("/sdcard", &host, &slot_config,
                            &mount_config, &card);
}

/* ===================== LOGGING ===================== */
static void log_event(uint8_t sensor_id,
                      const char *event,
                      sensor_data_t *data)
{
    FILE *f = fopen("/sdcard/log.txt", "a");
    if (!f) return;

    fprintf(f,
        "SENSOR=%d | T=%.2f | P=%.2f | H=%.2f | %s\n",
        sensor_id,
        data->temperature,
        data->pressure,
        data->humidity,
        event);

    fclose(f);
}

/* ===================== MAIN ===================== */
void app_main(void)
{
    ESP_LOGI(TAG, "System Init");

    i2c_init();
    motor_init();
    servo_init();
    sdcard_init();

    sensor_data_t data;

    while (1)
    {
        for (uint8_t i = 0; i < NUM_SENSORS; i++)
        {
            mux_select(i);
            read_bme280(&data);

            bool t = data.temperature > TEMP_THRESHOLD_C;
            bool p = data.pressure    > PRESSURE_THRESHOLD_HPA;
            bool h = data.humidity    > HUMIDITY_THRESHOLD_PCT;

            if (t || p || h)
            {
                motor_vibrate(1000);
                lateral_movement();
                log_event(i, "ALERT", &data);
            }

            if (t && p && h)
            {
                motor_vibrate(1500);
                lateral_movement();
                log_event(i, "CRITICAL", &data);
            }
        }

        vTaskDelay(pdMS_TO_TICKS(2000));
    }
}

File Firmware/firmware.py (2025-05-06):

# Bedsores Prevention System - Vibration Motor Fix
from machine import Pin, SoftI2C, PWM
import time
import bme280

# ========== HARDWARE CONFIGURATION ==========
# BME280 Sensor
I2C_SDA_PIN = 21
I2C_SCL_PIN = 22
i2c = SoftI2C(sda=Pin(I2C_SDA_PIN), scl=Pin(I2C_SCL_PIN))
bme = bme280.BME280(i2c=i2c)

# Vibration Motor (ERM) - Modified configuration
MOTOR_PIN = 13
motor = Pin(MOTOR_PIN, Pin.OUT)  # Simple digital control instead of PWM

# Servo Motor (SG90)
SERVO_PIN = 12
PWM_FREQ_SERVO = 50  # Standard 50Hz for servos
servo = PWM(Pin(SERVO_PIN), freq=PWM_FREQ_SERVO)

# ========== CALIBRATION ==========
# Servo Parameters
MIN_ANGLE = 0
MAX_ANGLE = 180
MIN_PULSE_US = 500
MAX_PULSE_US = 2500

# Threshold Values
TEMP_THRESHOLD = 32.0
PRESSURE_THRESHOLD = 1001.0
HUMIDITY_THRESHOLD = 80.0

# ========== ACTUATOR FUNCTIONS ==========
def vibrate(duration_ms=500):
    """Control vibration motor with digital output"""
    try:
        print("Activating vibration motor...")
        motor.value(1)  # Turn motor ON
        time.sleep_ms(duration_ms)
        motor.value(0)  # Turn motor OFF
        print("Vibration complete")
    except Exception as e:
        print("Vibration motor error:", e)
        motor.value(0)  # Ensure motor is off if error occurs

def test_vibration():
    """Test vibration motor function"""
    print("Testing vibration motor (3 pulses)...")
    for i in range(3):
        print(f"Pulse {i+1}...")
        vibrate(1000)  # 1 second on
        time.sleep(0.5)  # 0.5 second off

def set_servo_angle(angle):
    """Move servo to specified angle (0-180°) with protection"""
    try:
        angle = max(MIN_ANGLE, min(MAX_ANGLE, angle))
        pulse_us = MIN_PULSE_US + (angle * (MAX_PULSE_US - MIN_PULSE_US) / 180)
        duty = int(pulse_us * PWM_FREQ_SERVO * 65535 / 1_000_000)
        servo.duty_u16(duty)
        time.sleep_ms(300)  # Allow time to move
    except Exception as e:
        print("Servo error:", e)
        servo.duty_u16(0)

def lateral_movement():
    """Perform full lateral movement sequence"""
    print("Initiating lateral movement...")
    for angle in [45, 90, 135]:
        set_servo_angle(angle)
        vibrate(200)  # Small vibration during movement
        time.sleep(1)
    set_servo_angle(90)  # Return to center

# Run a simple test for the vibration motor
print("Bedsores Prevention System - Vibration Motor Test")
test_vibration()

# Now run the main system if you want
response = input("Continue with main program? (y/n): ")
if response.lower() == 'y':
    try:
        print("Starting main program...")
        while True:
            # Read and parse sensor data
            temp_str, press_str, hum_str = bme.values
            temp = float(temp_str[:-1])
            press = float(press_str[:-3])
            hum = float(hum_str[:-1])
            
            print(f"\nTemperature: {temp}°C | Pressure: {press}hPa | Humidity: {hum}%")
            
            # Check thresholds and trigger responses
            temp_high = temp > TEMP_THRESHOLD
            press_high = press > PRESSURE_THRESHOLD
            hum_high = hum > HUMIDITY_THRESHOLD
            
            if temp_high:
                print("High temperature detected")
                vibrate(1000)
                lateral_movement()
                
            if press_high:
                print("High pressure detected")
                vibrate(1000)
                lateral_movement()
                
            if hum_high:
                print("High humidity detected")
                vibrate(1000)
                lateral_movement()
            
            if temp_high and press_high and hum_high:
                print("Critical condition detected")
                vibrate(1500)
                lateral_movement()
            
            time.sleep(2)
    except KeyboardInterrupt:
        motor.value(0)
        servo.duty_u16(0)
        print("\nSystem safely stopped")
else:
    print("Test complete. System not started.")

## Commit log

2025-09-21 Create Prototypes
2025-09-21 Create KiCAD Design Files
    This contains all the circuit design and PCB design files
2025-09-21 Create KiCAD
2025-09-21 Create BOM
2025-09-21 Add files via upload
    Contains the curated list of components purchased for building a prototype
    [BOM.xlsx]
2025-09-21 Create STL files
    Contains STL files required for 3D printing the Electronics Design Case Enclosure
